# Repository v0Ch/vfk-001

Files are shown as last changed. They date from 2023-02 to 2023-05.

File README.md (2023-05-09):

# VFK-001
Valkyrie folded keyboard (folded vertical dactyl on full size mx silent swityches) with removable stabilizer
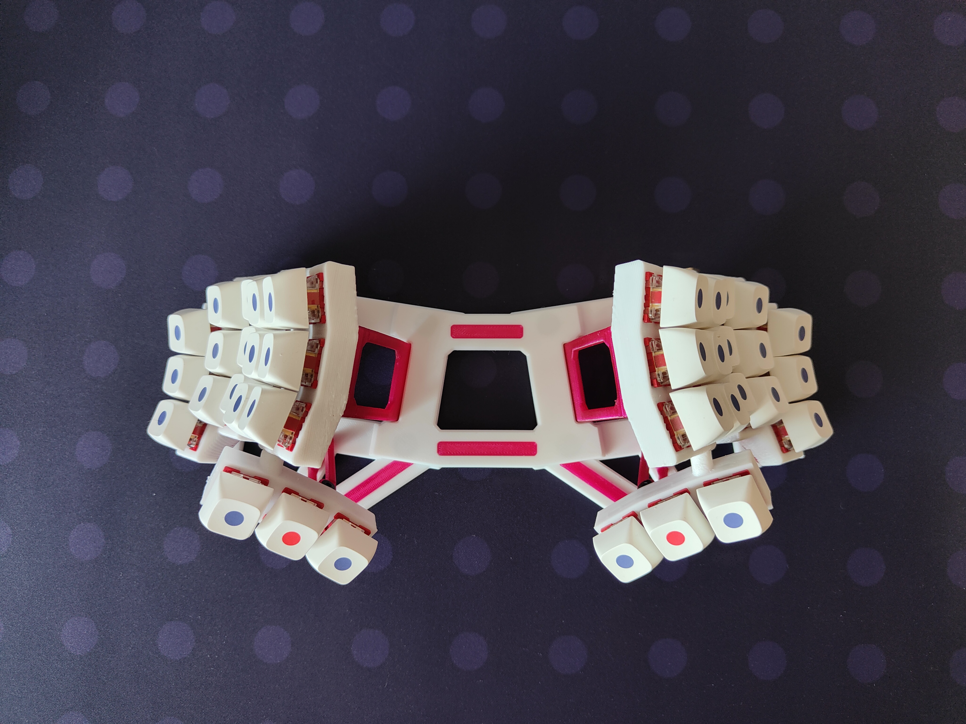
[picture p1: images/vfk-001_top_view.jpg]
VFK-001 top view


## Transformation
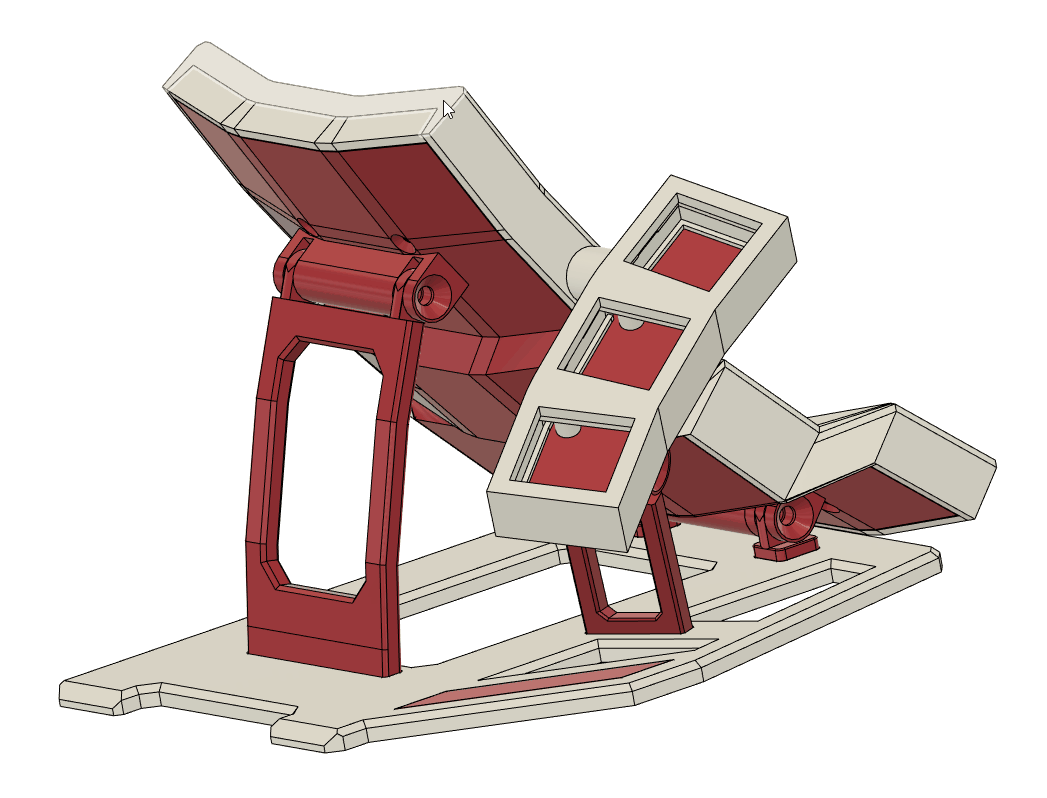
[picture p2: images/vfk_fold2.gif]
vfk_fold


## Pilot hands 
I don't use hovering of hands or wrist rests. When typing, I keep my wrists on the table.
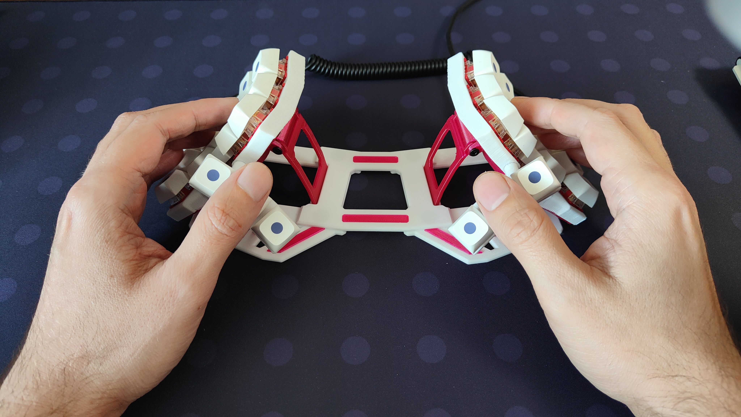
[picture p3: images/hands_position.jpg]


## BOM (BOM - Bill of Materials)
- 2 x Pro micro mcu
- 2 x Headphone Audio Socket PJ-320A
- 1 x 3.5 audio jack on 3.5 audio jack cable 
- 0.05 wire for hadnwires
- 36 x 1N4148 wire diodes
- 36 x Kailh hotswap socket 
- 36 x MX Switch (35g silent is best)
- Pet-g fillament, two colors :)
- 10 x m3 10mm hex screw (black is best)
- 16 x m2 5mm hex screw (black is best)
- 10 (14) x silicone bumpons 8mm 
- 8 x 10x2mm magnets for stabilizers mount

## Internal layout
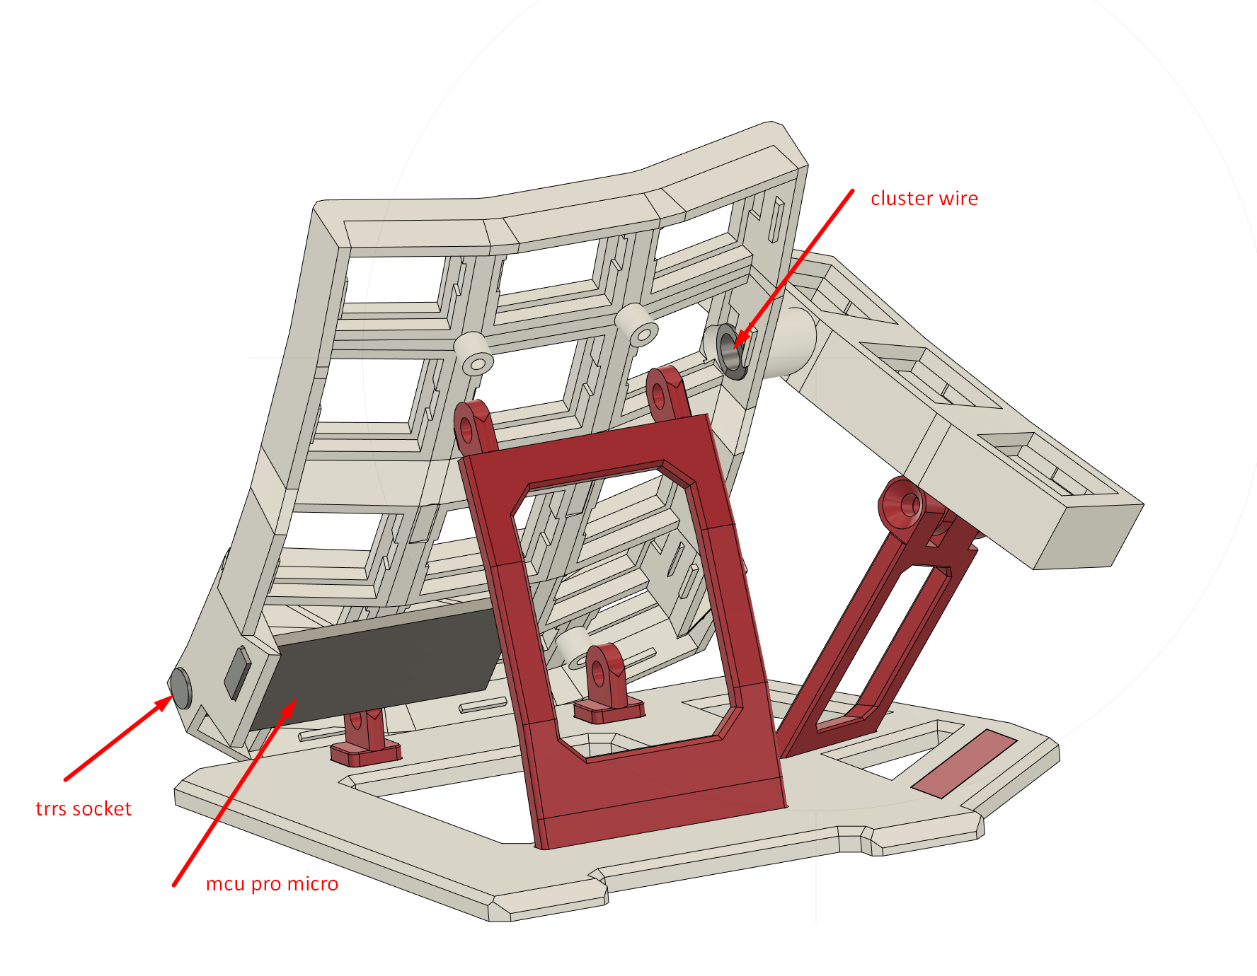
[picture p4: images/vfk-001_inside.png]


## Handwire matrix 
I'm building a matrix using sockets from kailh. Sockets give more reliability when soldering. Using a spatula to parse the phone, you can remove the switches without soldering. In this design, the bottom cover relies on the sockets too. The entire matrix is assembled from diodes. It works well.
matrix
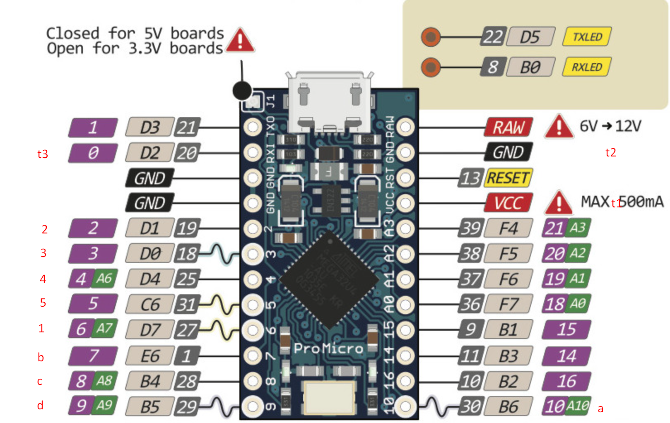
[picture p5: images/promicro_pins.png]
promicro


## Screws
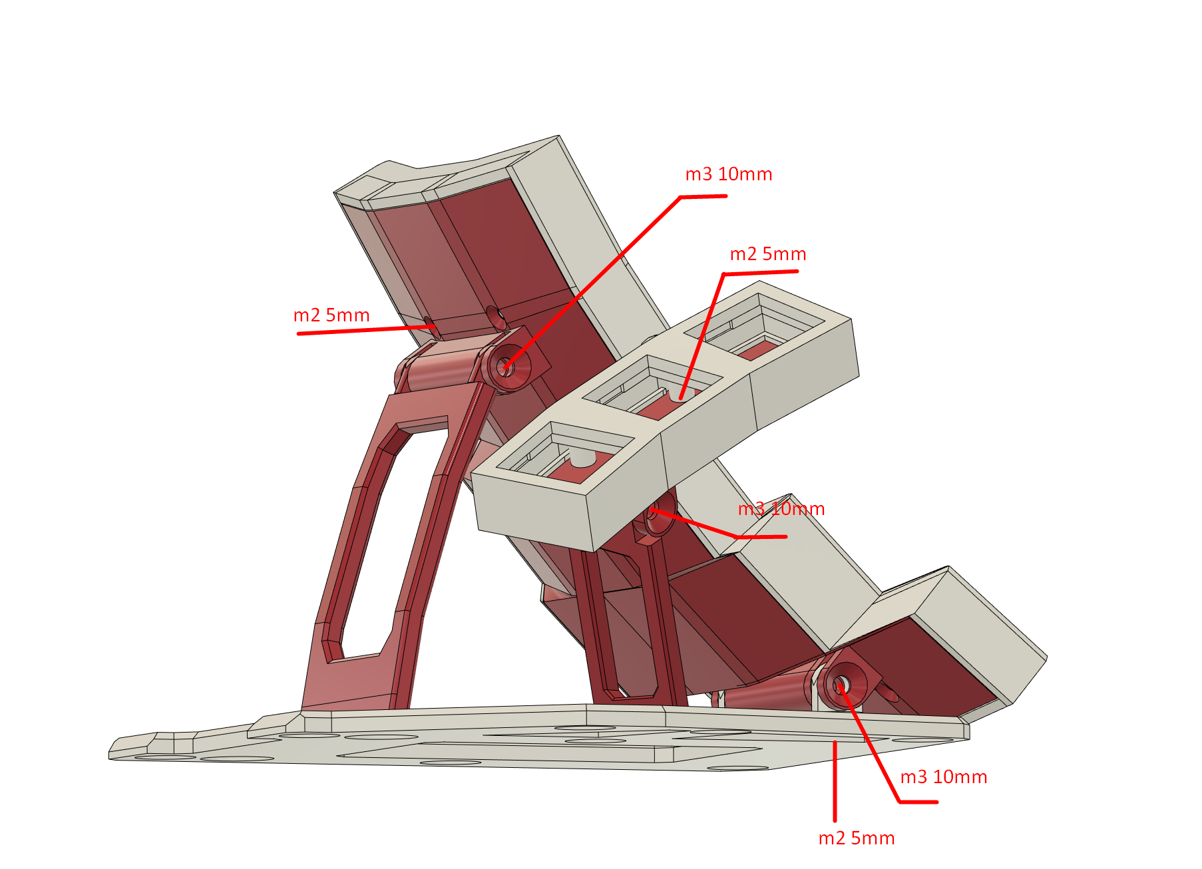
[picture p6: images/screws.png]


## Trackball option 
It was difficult. But I was able to add a trackball. It can still be folded, but the ball must be removed before folding.

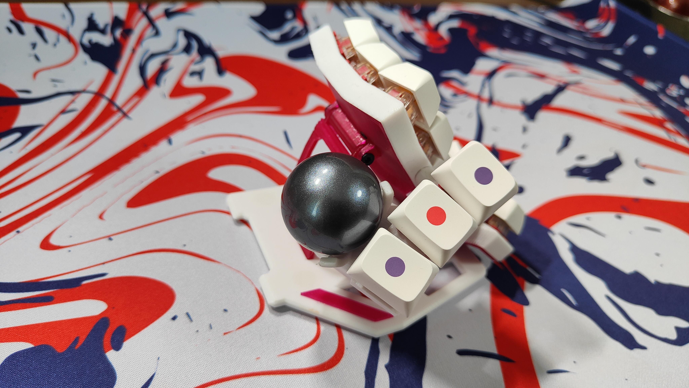
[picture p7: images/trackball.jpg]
Trackball cluster mod

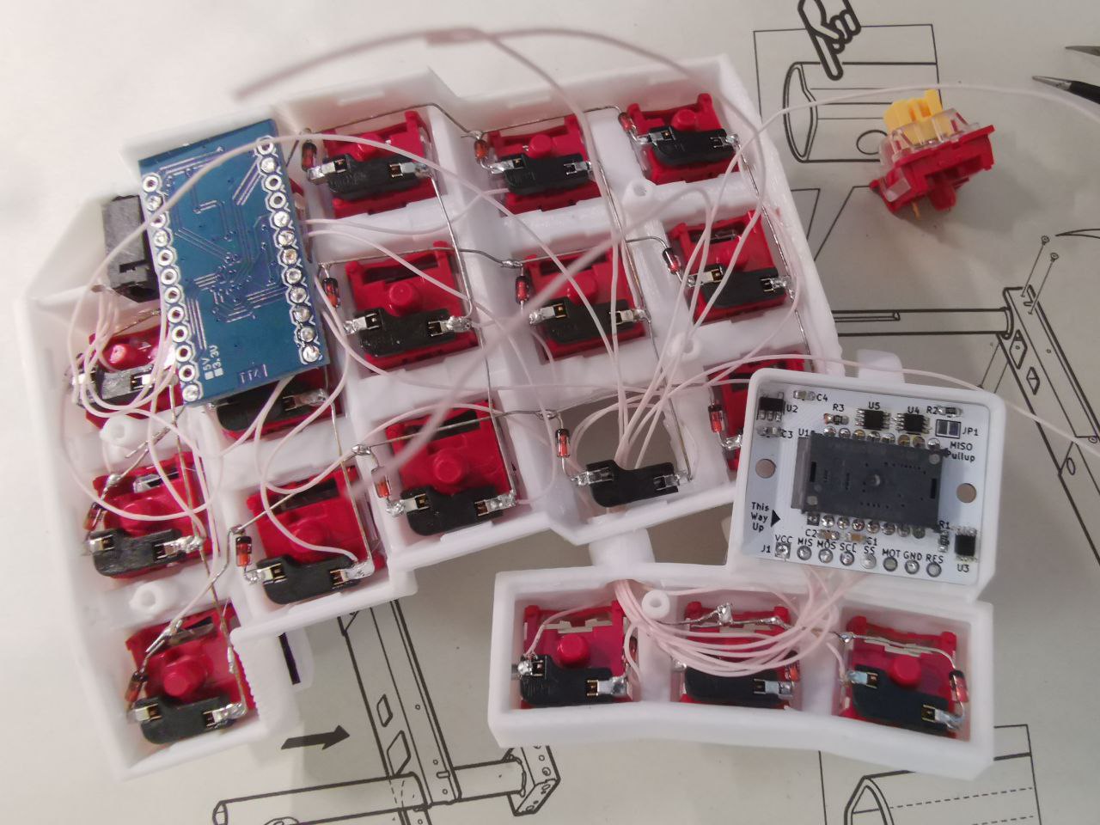
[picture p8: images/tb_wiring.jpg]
Trackball wiring

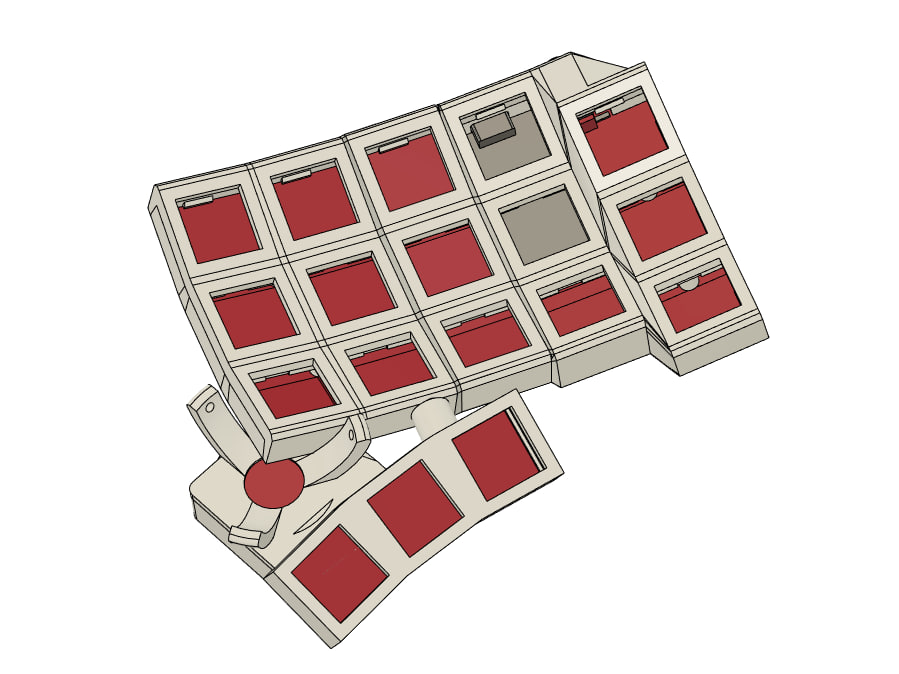
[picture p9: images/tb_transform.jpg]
Trackball folding


- I use Ogen project 3360 optical sensor - https://github.com/Ariamelon/Ogen 
- 34mm ball from Aliexpress
- 3 zrO2 ball static bearing

Cluster modifications file:
- Mofifed cluster in file - cluster tb.stl
- Trackball module bottom - cluster bottom tb.stl
- Full model with trackball cluseter - vfk-001 trackball 3360.step

## 3D Print
I used pet-g filament for printing and PrusaSlicer 2.5. I believe that it is necessary to use 3D glue to increase the adhesion of the printed table. I tried to make the keyboard as small as possible. Perhaps another filament will not be able to give the desired stiffness. It took me a while to print the arch and the bottom beautifully. Several models ended up in the trash can. I will attach a screenshot of the location of difficult to print models.
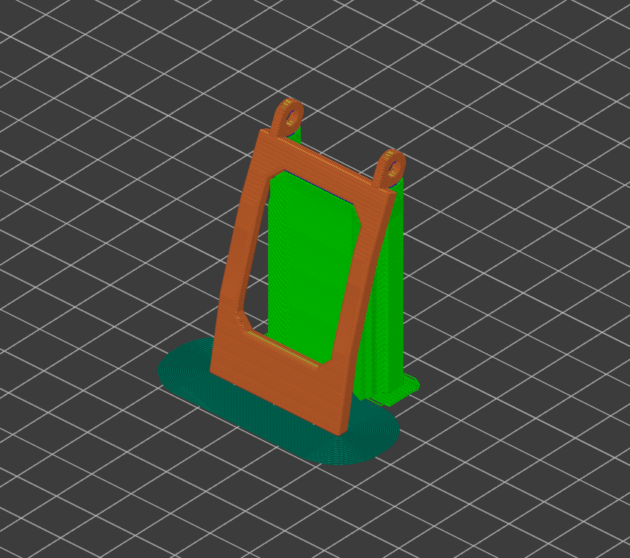
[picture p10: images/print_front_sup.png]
Print front support

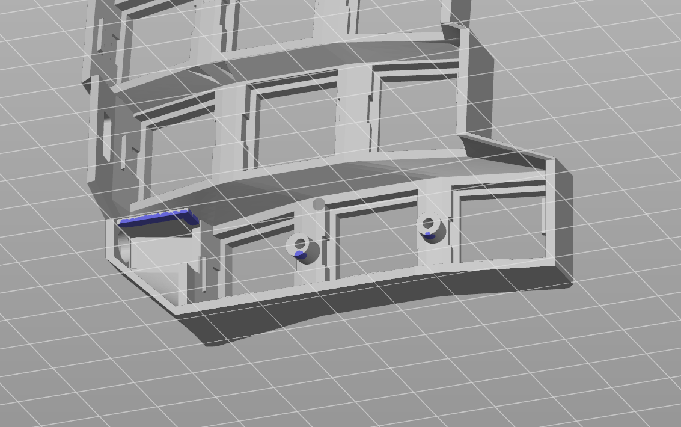
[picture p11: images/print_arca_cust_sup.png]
Print arca custom support

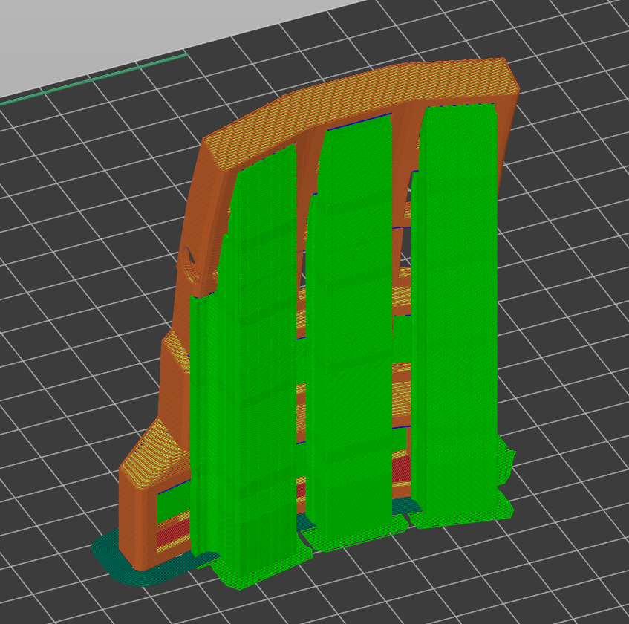
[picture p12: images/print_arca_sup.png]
Print arca

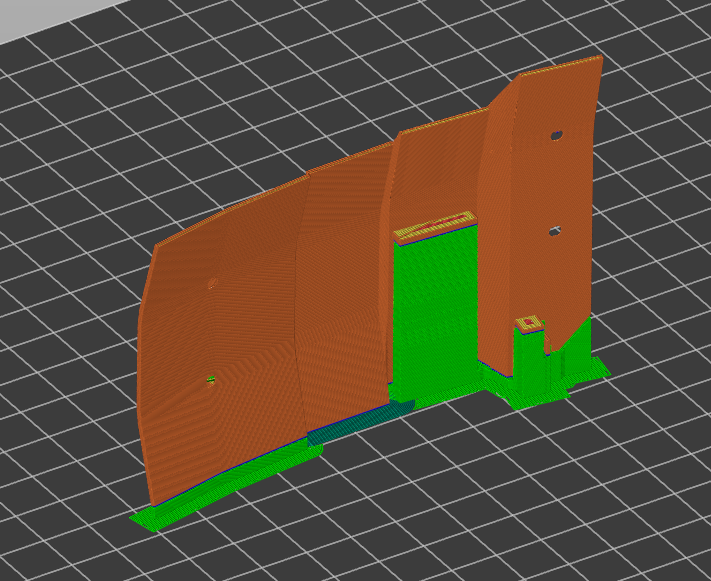
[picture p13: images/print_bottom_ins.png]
Print bottom 1

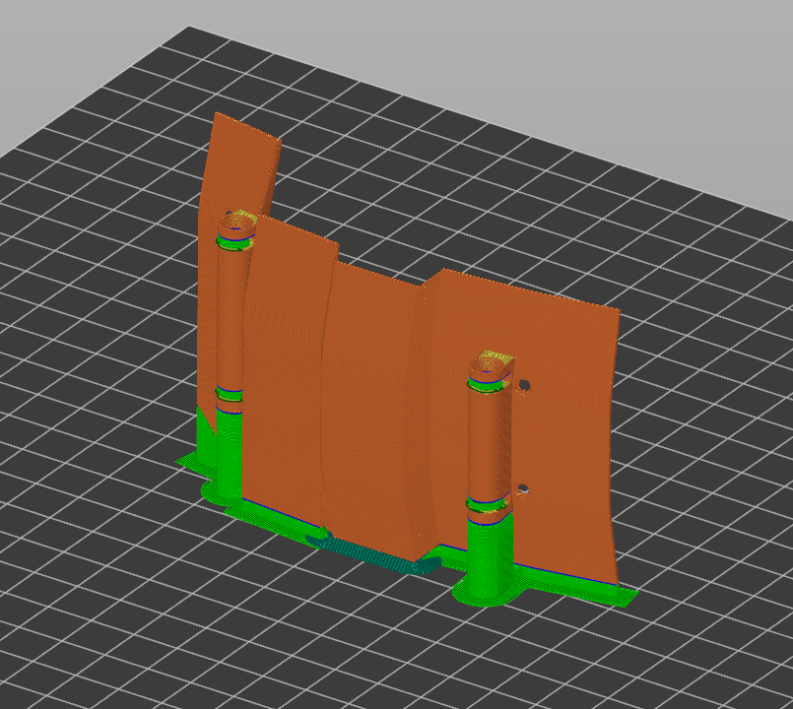
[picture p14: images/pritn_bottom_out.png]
Print bottom 2


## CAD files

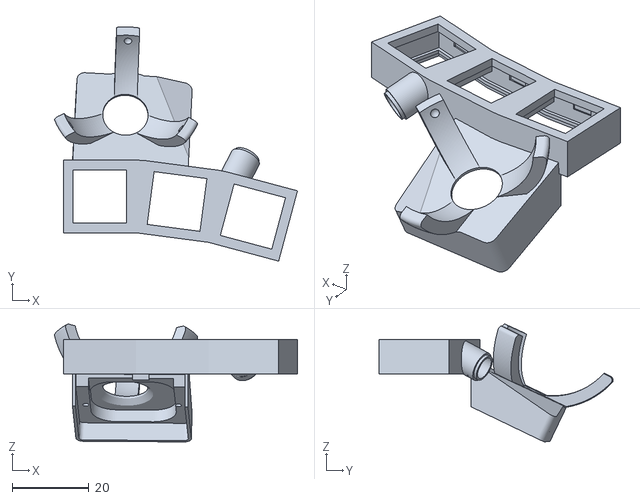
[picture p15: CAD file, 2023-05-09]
cluster tb.stl
63.4 x 61.2 x 30.8

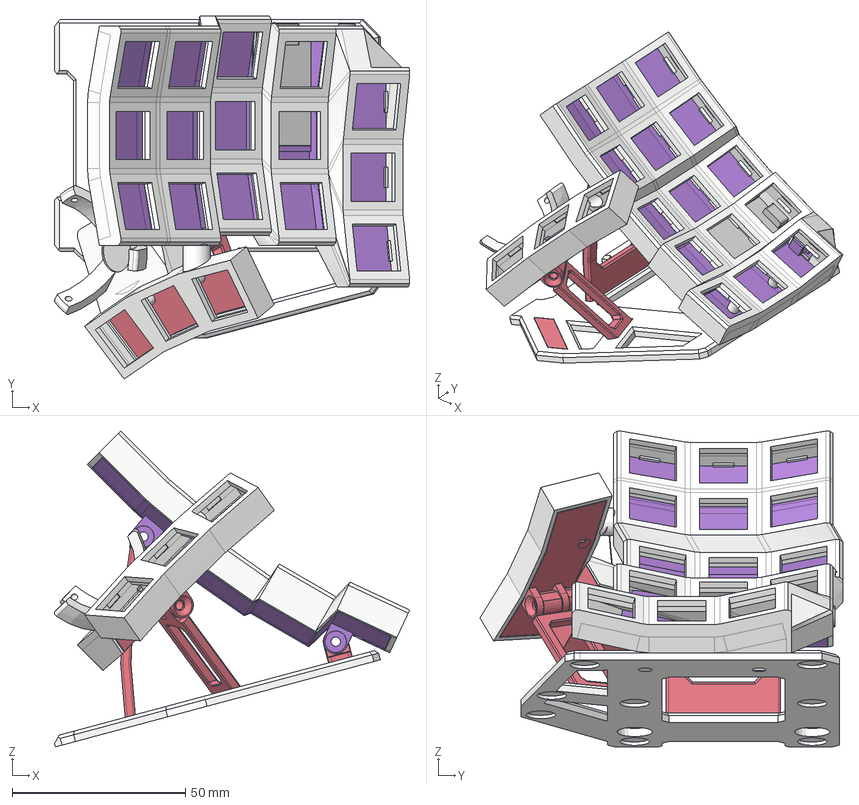
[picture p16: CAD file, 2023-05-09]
vfk-001 trackball 3360.step
102.4 x 104.6 x 91.0 mm
mcu
hp socket
arca (1)
holder
front support
bottom
cluster bottom
ogen_pcb_3360
cluster tb 3360
cluster support tb
cluster bottom tb

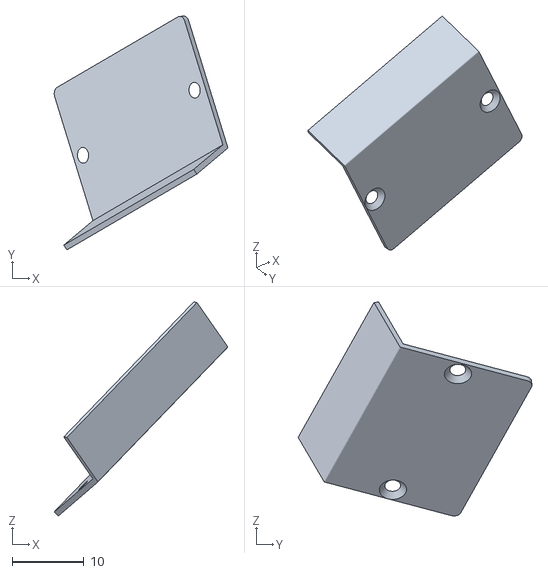
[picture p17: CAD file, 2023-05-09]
cluster bottom tb.stl
24.2 x 32.6 x 29.9

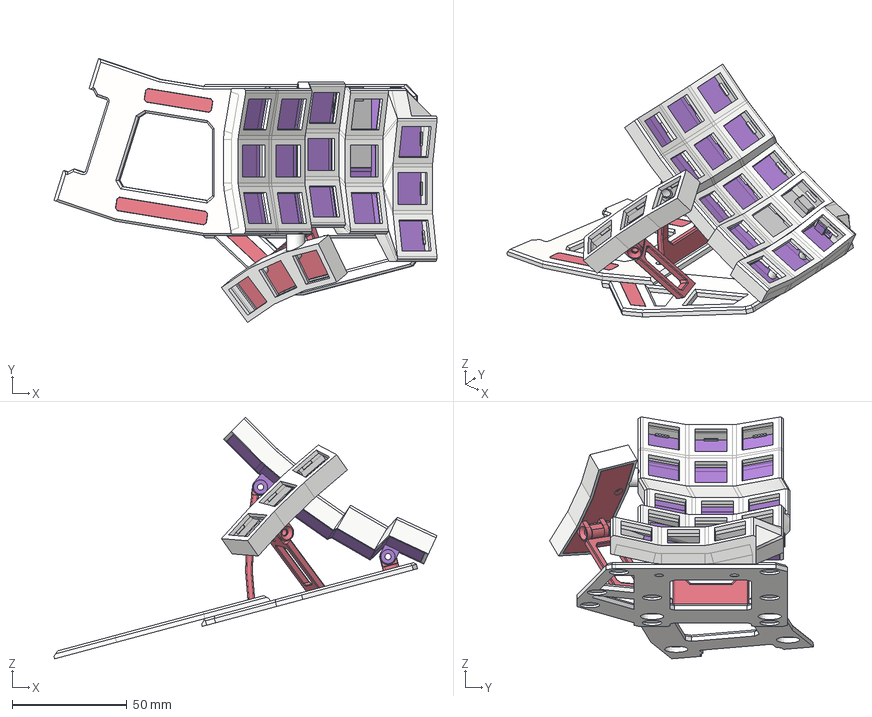
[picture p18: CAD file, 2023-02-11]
vfk-001.step
166.6 x 114.8 x 105.1 mm
mcu
hp socket
arca (1)
holder
front support
bottom
cluster
cluster bottom
cluster sleeve
cluster support
split hub compact

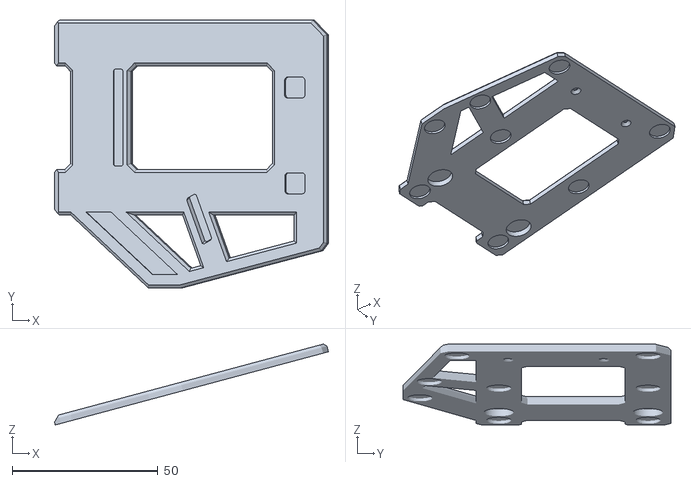
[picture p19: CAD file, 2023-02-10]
holder.stl
94.0 x 91.7 x 27.7

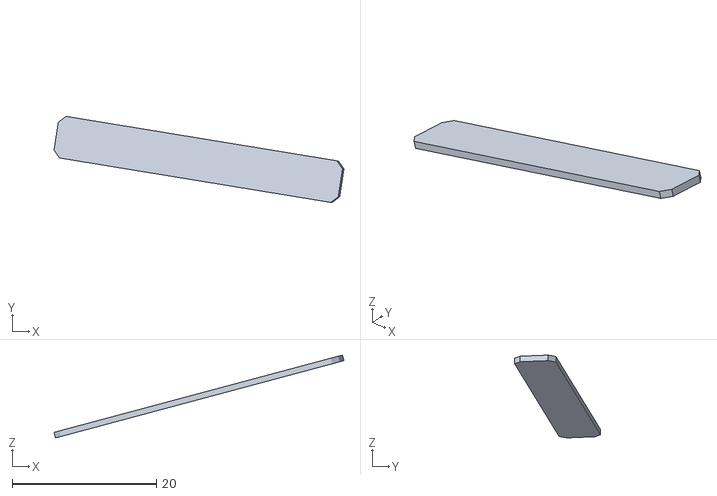
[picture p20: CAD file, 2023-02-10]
split hub compact mold bot18.stl
40.2 x 11.9 x 11.5

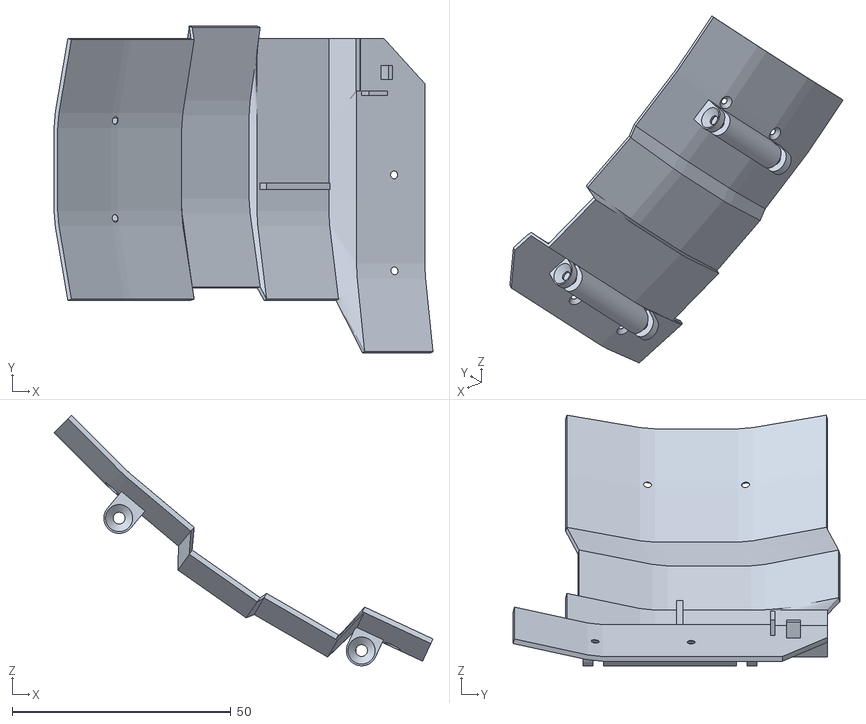
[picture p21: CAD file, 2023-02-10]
bottom.stl
86.7 x 74.7 x 57.3

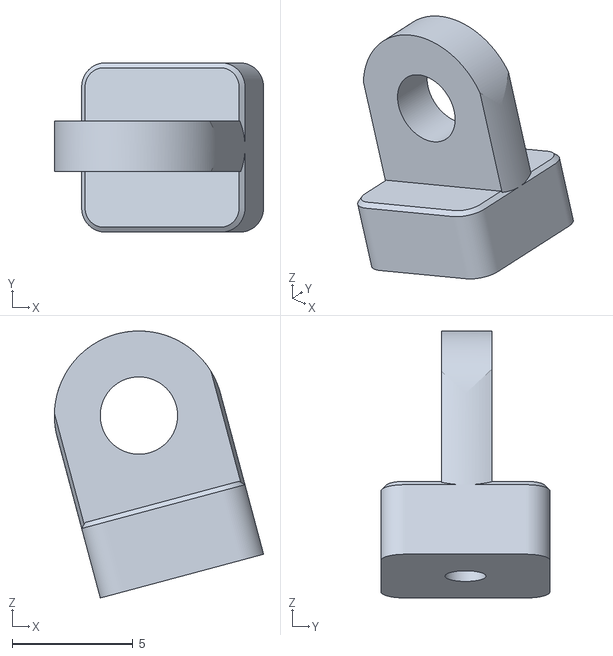
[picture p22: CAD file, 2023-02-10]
holder support 1.stl
8.66 x 7.00 x 11.1

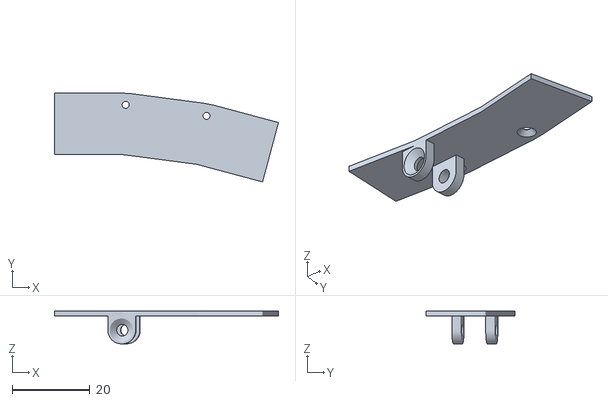
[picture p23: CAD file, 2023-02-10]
cluster botom.stl
57.5 x 22.8 x 8.40

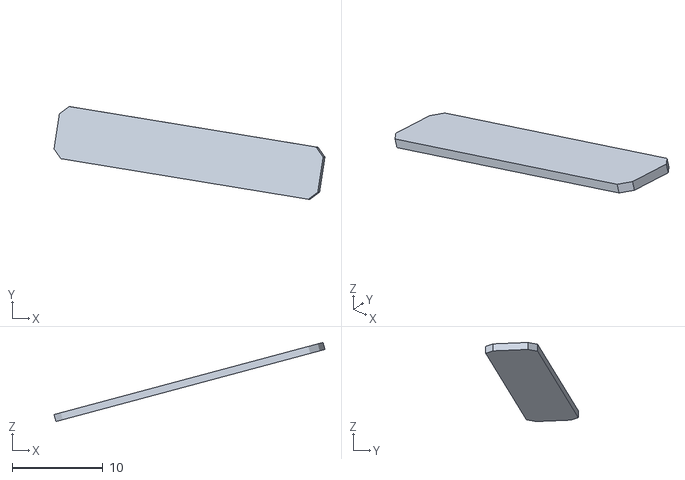
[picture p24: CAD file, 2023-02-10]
split hub compact mold top18.stl
29.9 x 10.2 x 8.72

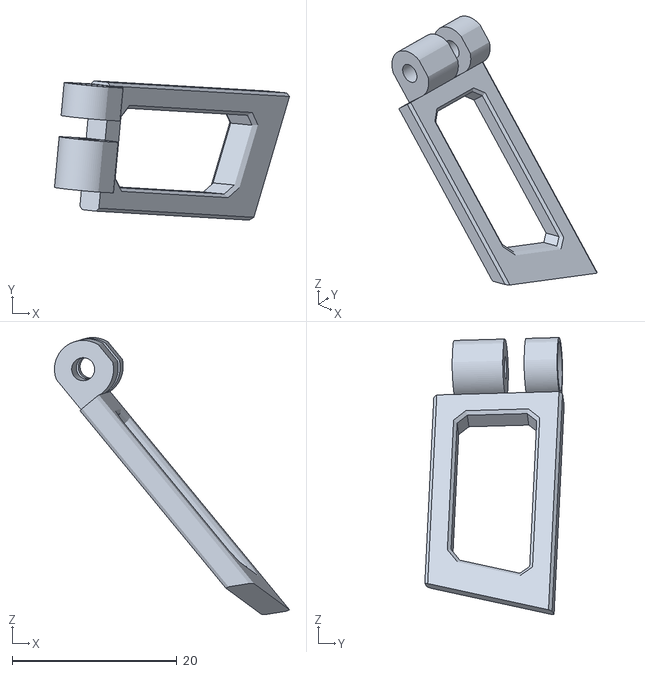
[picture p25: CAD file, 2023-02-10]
cluster support.stl
28.5 x 16.9 x 33.6

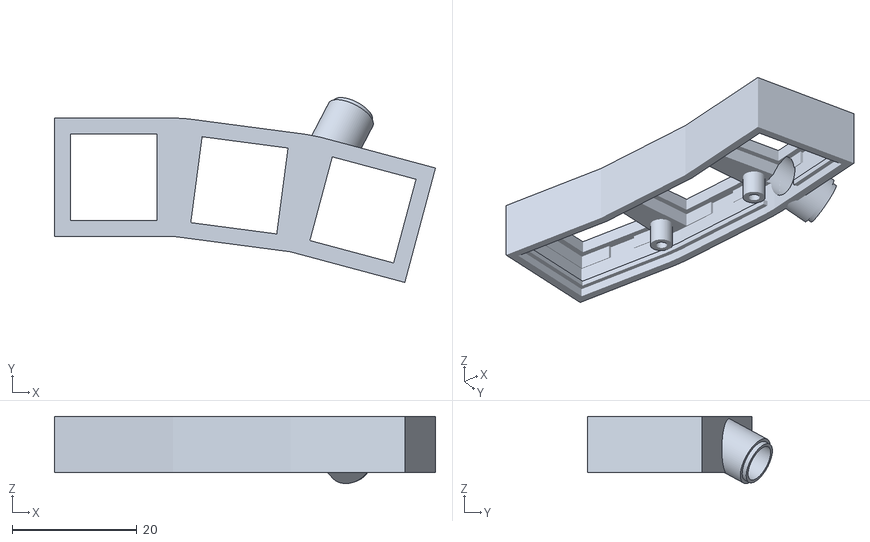
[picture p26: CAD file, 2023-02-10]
cluster.stl
61.1 x 29.7 x 10.8

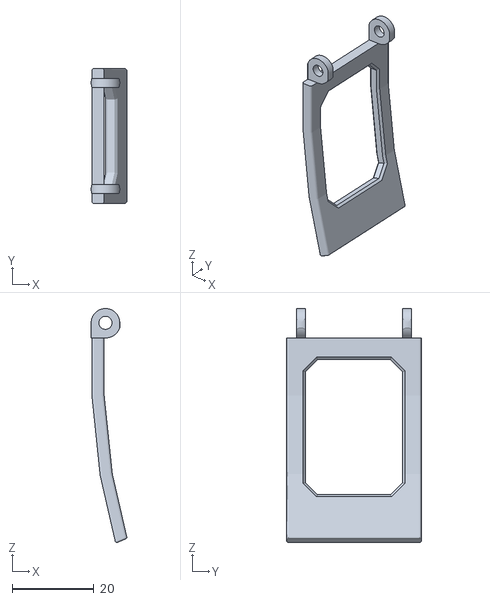
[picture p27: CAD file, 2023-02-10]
front support.stl
8.72 x 33.0 x 57.2

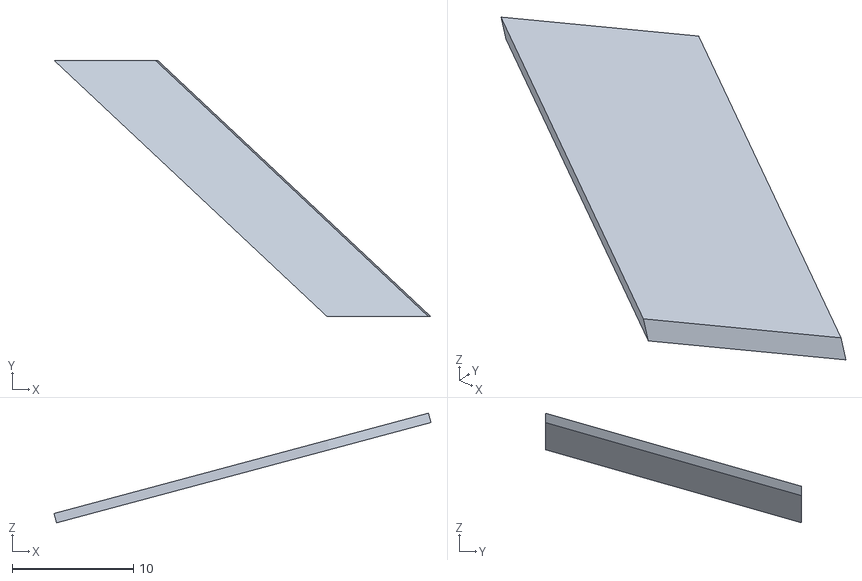
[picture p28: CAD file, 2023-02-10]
redline.stl
31.1 x 21.1 x 9.04

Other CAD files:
split hub compact 18.stl
holder support 2.stl
cluster sleve.stl

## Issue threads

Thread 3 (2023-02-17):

Choc switches

odama626, 2023-02-17:
this is more of a question than than an issue,

will this design work with kailh choc switches?  I'm also curious about going wireless and putting a battery in it but I'm not sure about the clearance of the case

v0Ch, 2023-02-18:
Can be built on choсs. Hole size allows I do not recommend. It won't be pretty. There will be ugly gaps in the columns. And most importantly noisy (no silent switch version). According to the discord, the Kailh are currently developing a silent version of the chokes. As soon as the silent version is available, I plan to make a special version for chocs. I didn't plan to build this wireless keyboard. There is no space for a battery in this design. I think the easiest way is to use xiao nrf52840 and a small battery. You can change the rear support of the mcu in my cover design (move it closer) and form a battery compartment under the 4th column.

moshpirit, 2024-11-11:
How come chock are noisier than MX?

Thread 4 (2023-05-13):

Fusion 360 files

MoneyPhobic, 2023-05-13:
Do you happen to have Fusion 360 files with each part separate? If you do, would you be willing to share them? Thanks! This keyboard looks amazing.

v0Ch, 2023-05-15:
I share step files. You can import them into fusion and view and modify as you see fit. This is the exact format of solids as opposed to stl. Source files and fusion format contain a lot of traces of experiments, dead ends and dirt. I don't want to share this.

MoneyPhobic, 2023-05-16:
Thank you! One more question: Could you share a link to where you bought the zrO2 ball static bearings?

v0Ch, 2023-05-17:
2mm https://www.aliexpress.us/item/2255799954930564.html

MoneyPhobic, 2023-05-17:
TYSM!

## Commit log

2023-02-11 Add step file
    [vfk-001.step]
2023-02-11 print img manual
2023-05-09 Trackball 3360 extra cluseter
    [cluster bottom tb.stl, cluster tb.stl, vfk-001 trackball 3360.step]
